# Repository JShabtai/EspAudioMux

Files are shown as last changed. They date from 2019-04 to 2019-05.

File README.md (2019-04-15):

# Intro

This project uses an ESP8266 and a 74HC4052 to control 4 stereo audio channels.

# Build/flash

## Requirements

The following tools are required and must be available on your PATH

* nodemcu-tool
* esptool

To run this on your ESP8266, flash the NodeMcu firmware that is pre-compiled and available in this repo.
To do this you must first put the ESP8266 into flashing mode. To do this, hold the flashing button on your
module (which is connected to GPIO0) and press the reset button. Then run the following:

```
make flash
```

Once that's done successfully, you need to upload the lua files:

```
make upload
```

# How to use

When the module boots up it will attempt to connect to a WiFi network if it already knows about one. If that fails,
then it will automatically enter WPS mode. Simply press the WPS button on your router then restart the ESP8266.
The EPS8266 will get the Wi-Fi credentials and connect automatically. This only needs to be done once - the
credentials are remembered.

You will need to know the IP of your device to connect to it. When the device connects to a Wi-Fi network it will
print out its IP address. Use the following command to restart the device (forcing it to re-connect)

```
make restart terminal
```

You will see a line something like this:

```
Connected to WIFI with IP: 192.168.0.101
```

It is recommended that you add a DHCP reservation on your router to keep the IP from changing, so you don't need to
repeat these steps. If your router supports this, then consult your routers documentation for instructions.

By default the MUX is off, and channel 0 is selected.

## API

The module exposes a few simple endpoints to control the MUX:

* `/enable`: Turn the MUX on.
* `/disable`: Turn the MUX off.
* `/channel/x`: Select channel `x`, where `x` is between 0 and 3 inclusive

# Future improvements

* Add LEDs to indicate which channel is active or if the device is off
* Add physical button to switch the channel manually
* Remember MUX status (on/of and channel)

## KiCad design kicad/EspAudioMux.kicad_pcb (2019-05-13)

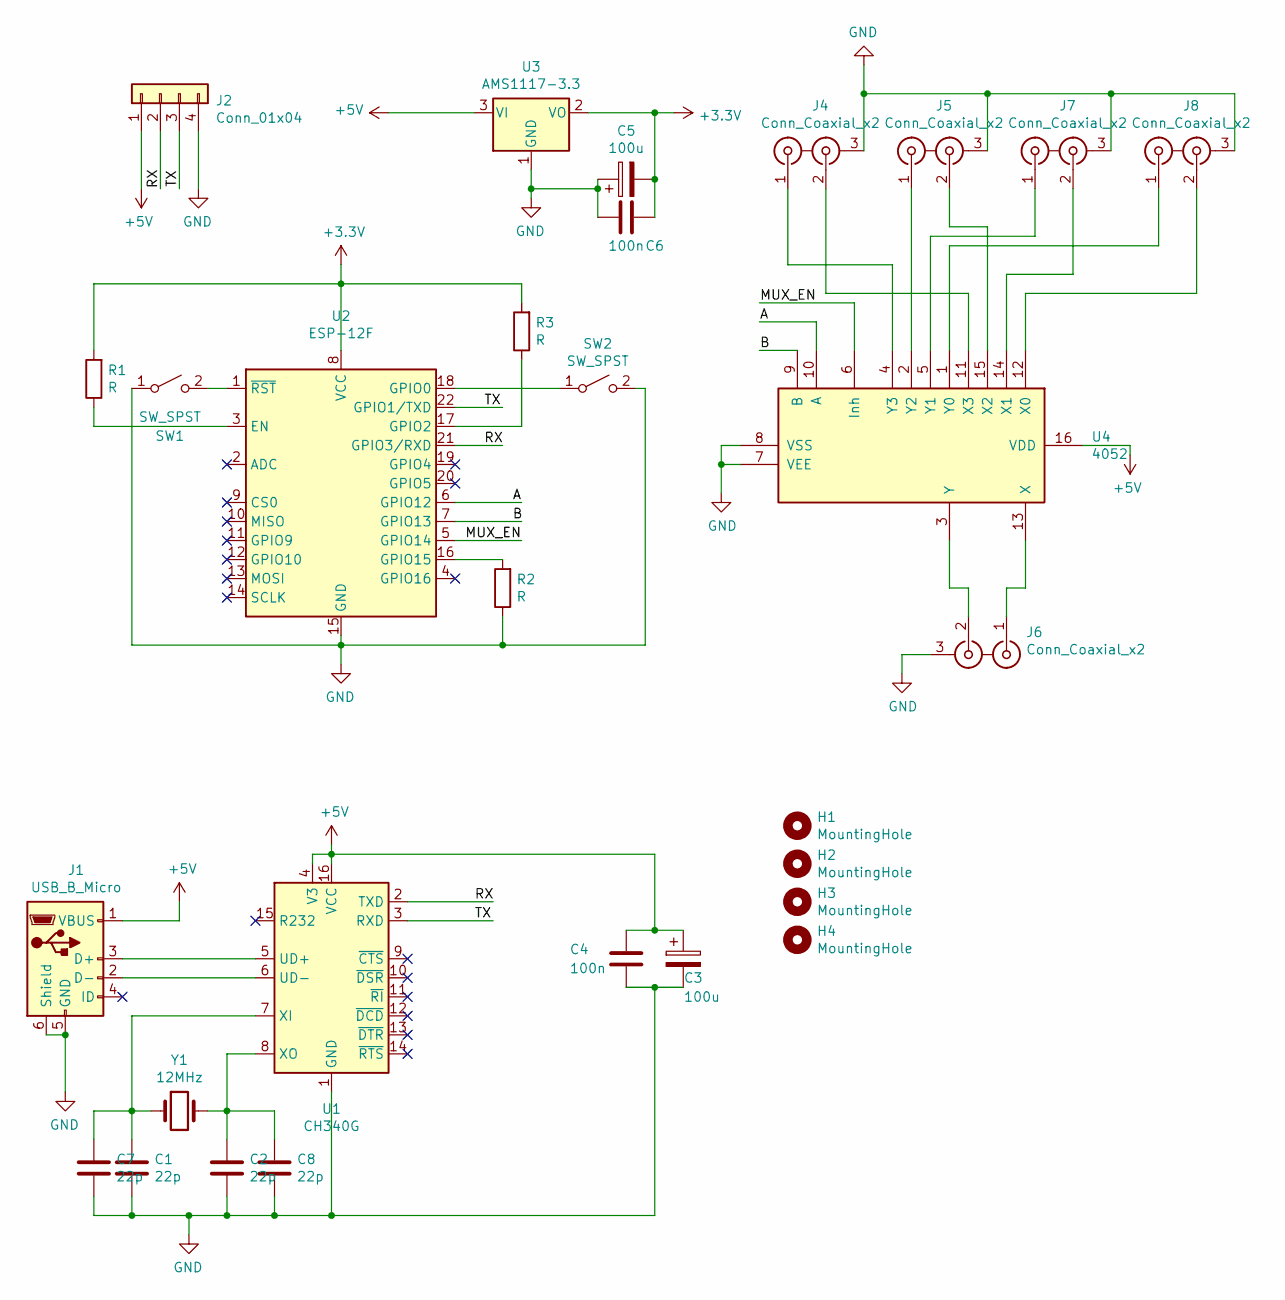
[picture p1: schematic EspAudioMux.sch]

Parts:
C1, C2: 22p; C_0603_1608Metric_Pad1.05x0.95mm_HandSolder
C3, C5: 100u; CP_Radial_D8.0mm_P2.50mm
C4, C6: 100n; C_0603_1608Metric_Pad1.05x0.95mm_HandSolder
C7, C8: 22p; C_Disc_D3.0mm_W1.6mm_P2.50mm
H1, H2, H3, H4: MountingHole; MountingHole_2.2mm_M2
J1: USB_B_Micro; USB_Micro-B_Wuerth_629105150521_CircularHoles
J2: Conn_01x04; PinHeader_1x04_P2.54mm_Vertical
J4, J5, J6, J7, J8: Conn_Coaxial_x2; RCA_3.5mm
R1, R2, R3: R; R_0603_1608Metric_Pad1.05x0.95mm_HandSolder
SW1, SW2: SW_SPST; SW_SPST_EVQP0
U1: CH340G; SOIC-16_3.9x9.9mm_P1.27mm
U2: ESP-12F; ESP-12E
U3: AMS1117-3.3; SOT-223-3_TabPin2
U4: 4052; DIP-16_W7.62mm_Socket_LongPads
Y1: 12MHz; Crystal_HC18-U_Vertical

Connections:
+3V3: C5.2, C6.1, R1.2, R3.2, U2.8 (VCC), U3.2 (VO)
+5V: C3.1, C4.2, J1.1 (VBUS), J2.1, U1.4 (V3), U1.16 (VCC), U3.3 (VI), U4.16 (VDD)
/A: U2.6 (GPIO12), U4.10 (A)
/B: U2.7 (GPIO13), U4.9 (B)
/MUX_EN: U2.5 (GPIO14), U4.6 (Inh)
/RX: J2.2, U1.2 (TXD), U2.21 (GPIO3/RXD)
/TX: J2.3, U1.3 (RXD), U2.22 (GPIO1/TXD)
GND: C1.2, C2.2, C3.2, C4.1, C5.1, C6.2, C7.2, C8.2, J1.5 (GND), J1.6 (Shield), J2.4, J4.3 (EXT), J5.3 (EXT), J6.3 (EXT), J7.3 (EXT), J8.3 (EXT), R2.1, SW1.1 (A), SW2.2 (B), U1.1 (GND), U2.15 (GND), U3.1 (GND), U4.7 (VEE), U4.8 (VSS)
unnamed: C1.1, C7.1, U1.7 (XI), Y1.1
unnamed: C2.1, C8.1, U1.8 (XO), Y1.2
unnamed: J1.2 (D-), U1.6 (UD-)
unnamed: J1.3 (D+), U1.5 (UD+)
unnamed: J4.1 (IN1), U4.4 (Y3)
unnamed: J4.2 (IN2), U4.11 (X3)
unnamed: J5.1 (IN1), U4.2 (Y2)
unnamed: J5.2 (IN2), U4.15 (X2)
unnamed: J6.1 (IN1), U4.13 (X)
unnamed: J6.2 (IN2), U4.3 (Y)
unnamed: J7.1 (IN1), U4.5 (Y1)
unnamed: J7.2 (IN2), U4.14 (X1)
unnamed: J8.1 (IN1), U4.1 (Y0)
unnamed: J8.2 (IN2), U4.12 (X0)
unnamed: R1.1, U2.3 (EN)
unnamed: R2.2, U2.16 (GPIO15)
unnamed: R3.1, U2.17 (GPIO2)
unnamed: SW1.2 (B), U2.1 (~RST)
unnamed: SW2.1 (A), U2.18 (GPIO0)

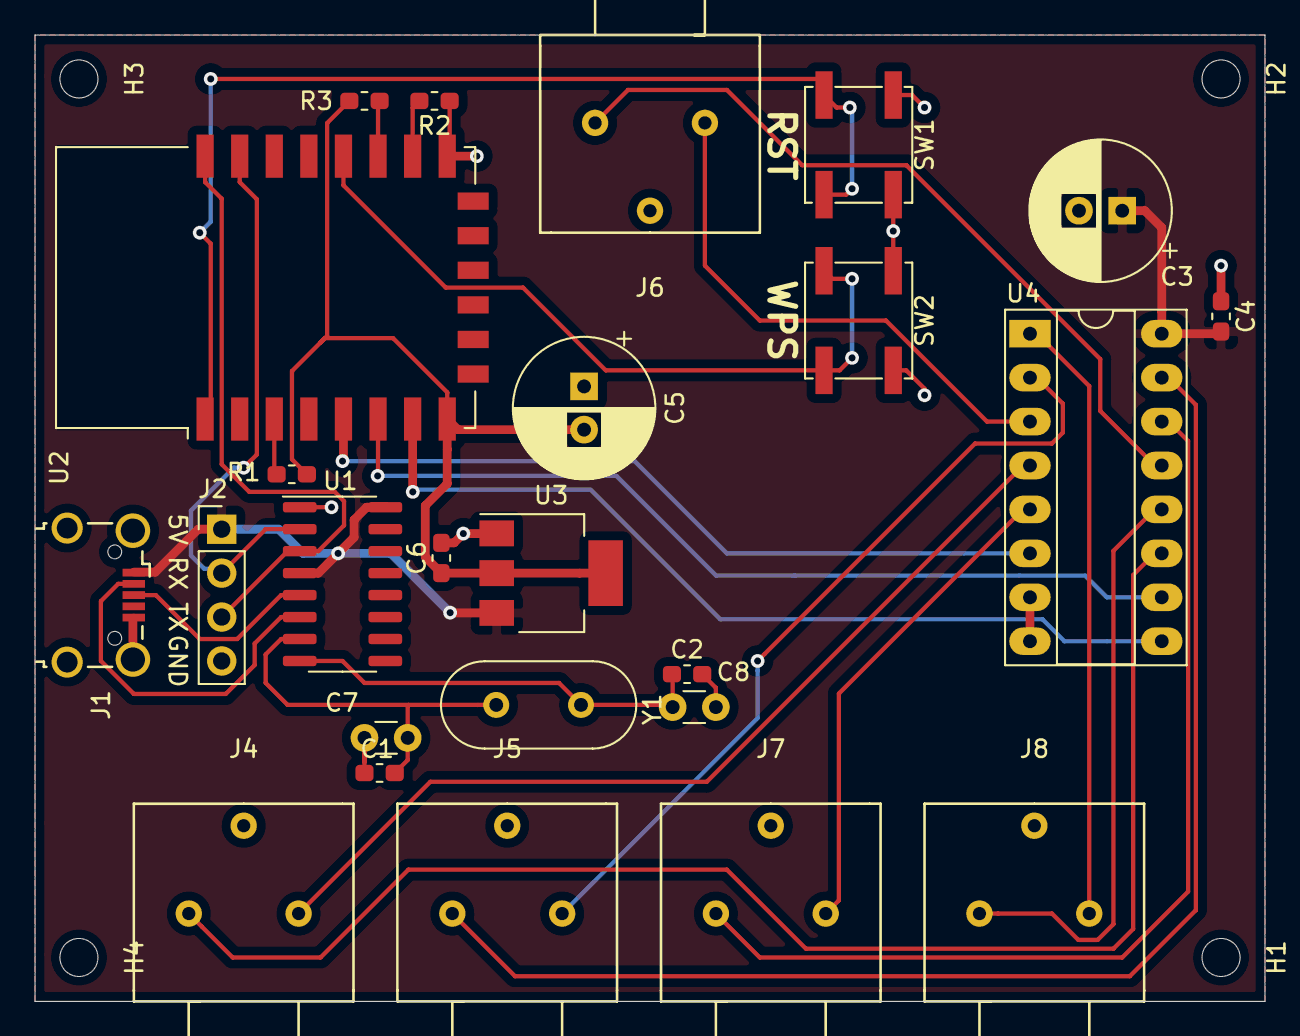
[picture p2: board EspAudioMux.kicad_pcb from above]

Board: 2 copper layers, 71.1 x 55.9 mm, 29 parts (0 on the bottom side), 27 nets.

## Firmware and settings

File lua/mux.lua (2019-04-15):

enablePin = 5
s0Pin = 6
s1Pin = 7

muxEnabled = false
muxCurrentChannel = 0

function muxEnable(enable)
    muxEnabled = enable
    if (enable) then
        gpio.write(enablePin, gpio.LOW)
    else
        gpio.write(enablePin, gpio.HIGH)
    end
end

function muxSetChannel (channel)
    if (channel == 0) then
        gpio.write(s0Pin, gpio.LOW)
        gpio.write(s1Pin, gpio.LOW)
    elseif (channel == 1) then
        gpio.write(s0Pin, gpio.HIGH)
        gpio.write(s1Pin, gpio.LOW)
    elseif (channel == 2) then
        gpio.write(s0Pin, gpio.LOW)
        gpio.write(s1Pin, gpio.HIGH)
    elseif (channel == 3) then
        gpio.write(s0Pin, gpio.HIGH)
        gpio.write(s1Pin, gpio.HIGH)
    else
        return
    end

    muxCurrentChannel = channel
end

gpio.mode(enablePin, gpio.OUTPUT)
gpio.mode(s0Pin, gpio.OUTPUT)
gpio.mode(s1Pin, gpio.OUTPUT)

muxEnable(false)
muxSetChannel(0)

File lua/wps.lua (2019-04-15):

wpsConnecting = false
function connectWps ()
    if (wpsConnecting) then
        print('WPS connection already in progress')
        return
    end

    wpsConnecting = true
    print('Beginning WPS push button connection')

    wifi.setmode(wifi.STATION)
    wps.enable()

    wps.start(function(status)
        if status == wps.SUCCESS then
            wps.disable()

            print("WPS: Success, connecting to AP...")

            wifi.sta.connect(function()
                -- TODO Check and handle status
                wpsConnecting = false
                print ("Done (possibly unsuccessfully)")
            end)
            return
        end

        wps.disable()
        wpsConnecting = false
    end)
end

-- GPIO0 (used for flashing) is IO pin 3
gpio.mode(3, gpio.INPUT)
gpio.trig(3, 'up', connectWps)

-- Try connecting normally. If this fails, automatically start WPS
print('Trying to connect to Wi-Fi')
wifi.sta.connect(function()
    status = wifi.sta.status()
    if (status == wifi.STA_GOTIP) then
        print ("Connected to Wi-Fi")
        return
    elseif (status == wifi.STA_CONNECTING) then
        print ("Wi-Fi is connecting")
        return
    elseif (status == wifi.STA_IDLE) then
        print ("Wi-Fi is idle")
    elseif (status == wifi.STA_WRONGPWD) then
        print ("Wi-Fi password is wrong")
    elseif (status == wifi.STA_APNOTFOUND) then
        print ("Cannot find a known AP")
    elseif (status == wifi.STA_FAIL) then
        print ("Wi-Fi connection failed")
    else
        print ("Connection status unknown")
    end

    connectWps()
end)

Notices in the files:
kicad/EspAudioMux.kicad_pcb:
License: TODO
